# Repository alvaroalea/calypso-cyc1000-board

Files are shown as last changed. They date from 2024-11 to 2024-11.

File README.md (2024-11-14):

# The calypso board project

Calypso is just another middleboard based on the Arrow/Trenz cyc1000 board. This was born as a personal project to experiment with such board as it was delivered by Arrow Electronics as part of their European "Jump Start" Program for FPGAs.

THIS FORK is only to try to got a cheap way to order pcb with SMD components solder, please refer to the original project for any:

https://github.com/teiram/calypso-cyc1000-board

## Prices:
### 5 QTY
|Type of build: |  |  /5 |
|----|----|----|
|Only PCB | 1,89€+1,43€ = 4€ |  1€ |
|All smd (71)(but no 1 resistor, transistors, PCM5102, usb socket) |  43,25€+17,43€ =  61€ |  12€ |
|Only basic smd components + Diodes (62)(no 1C, 9R, 2Q, PCM, usb ) |  19,63€+17.xx€ =  38€ |  8€ |
|Only basic smd components (52)(previos - diodes) |  15,97€+16,68€ =  33€ |  7€ |

### 2QTY + 3 PCB
|Type of build: |  |  /2 |
|----|----|----|
|All smd (71)(but no 1 resistor, transistors, PCM5102, usb socket) | 40,75€+16,68€=57€-3€=55€ |  27€ |

### 20 QTY
|Type of build: |  |  /20 |
|----|----|----|
|All smd (71)(but no 1 resistor, transistors, PCM5102, usb socket) |  82,93€+42,74€ = 126€ |  6.5€ |
|Only basic smd components + Diodes  (62)(no 1C, 9R, 2Q, PCM, usb ) |  51,09€+41,41€ =  93€ |  5€ |

### 10 QTY
|Type of build: | |  /10 |
|---|---|---|
|All smd (71)(but no 1 resistor, transistors, PCM5102, usb socket)  | 53,17€+26,89€ =  80€ |  8€ |
|Only basic smd components + Diodes  (62)(no 1C, 9R, 2Q, PCM, usb ) | 27,19€+26,06€ =  54€ |  5.5€ |

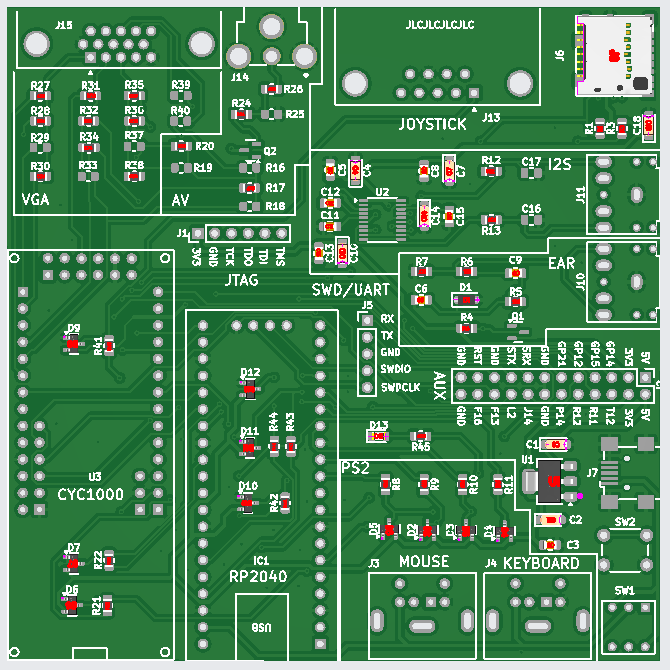
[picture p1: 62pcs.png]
Most economical option


# Original Doc:

The board takes ideas and design from other existing hobbyist project boards, embracing the following design principles:
- Doesn't try to support multiple FPGAs and/or MCUs. it's based on the CYC1000 board and an R2040 as MCU
- Follows the Mist ideas about IO, being the MCU the hub for most IO needs. This is convenient since the CYC1000 doesn't expose a big number of pins to the outside world.
- Tries to be compatible to some extent with Mist IO, therefore exposing a SPI bus mastered by the MCU to the FPGA, and the well known select signals CONF_DATA0, MIST_SS2, MIST_SS3 and MIST_SS4. This should ease the task of porting cores from Mist or boards with a similar design.
# Features
- VGA444 output via an standard VGA DB15 connector
- Optional AV output via a RCA connector. Both VGA and AV share FPGA pins.
- DB9 connector for a joystick with up to 2 fire buttons
- SD card
- Two PS/2 connectors
- Power button
- Reset button
- Ear input
- I2S audio output
- Mini USB for main power supply
- AUX connector for extension, exposing free pins in both the Cyc1000 and the RP2040.

# Pinout
As of preview version 0.2 this is the pinout description

Pinout Calypso Pinouts

# Support firmware
Firmware for the RP2040 MCU is so far a fork of zxmicrojack for RP2040 based Mist (https://github.com/ZXMicroJack/mist-firmware-rp2040) modified for calypso. The aim is to develop a specific and more minimalistic firmware since the current one was used mostly for board validation purposes. The forked firmware can be found here: https://github.com/teiram/mist-firmware-rp2040 

> [!NOTE]  
> I'm happy to share that we have now an oficial firmware for the board. It's still in a preliminary stage but should support most of the needed feature for Mist compatibility > and you can find it here: https://github.com/teiram/calypso-firmware/

# Disclaimer
This is a personal project I started with the support of the RetroWiki FPGA Dev community (thank you guys). There is no aim for commercial benefit neither I will provide any warranty or support beyond what my free time allows for. Feel free to build the board for your personal use, or a limited batch of units for your pals. It works for me, but I tested it with a very limited set of hardware, so your milleage may vary.
Enjoy ;)

# Errata, issues
## Version 0.3
- Fixed Q2 footprint and updated values for C16 and C17. This version is so far untested, but since Q2 issue was fixed manually without need ro reroute the board again, there are good chances it's safe to use.
  
## Version 0.2
- Q2 footprint is wrong. The schematic shows a BC547 but a SMD BC847 was intended. Unfortunately the pinout doesn´t match. So in case you want to use the composite video output you need to adjust it accordingly. A BC847 can be installed by rotating it 90º counterclockwise, what makes soldering a bit trickier but it can be done.
- The board supports RP2040 clones known as YD-2040 by VCC-GND studio. An official RP2040 won´t work completely due to:
  - The SWD header in the official RP2040 has 3 pins instead of 4 pins, so you cannot take advantage of the SWD/UART connector but you can still attach your SWD device directly to the RP2040.
  - YD-2040 exposes GPIO 23 on pin 37, which is not the case for in the official RP2040. Unfortunately GPIO23 is used for one of the DB9 joystick directions, and therefore a DB9 joystick won't work properly with an official RP2040
  - The YD-2040 doesn´t expose VBUS on the breakboard pins, therefore USB devices can only be used if they are self-powered or connected through a self-powered USB hub. The official RP2040 exposes VBUS and therefore it would be possible to power the bus without the need of a powered hub. But since the design was based on the YD-2040 there is no provision for that. This might be addressed in future releases.

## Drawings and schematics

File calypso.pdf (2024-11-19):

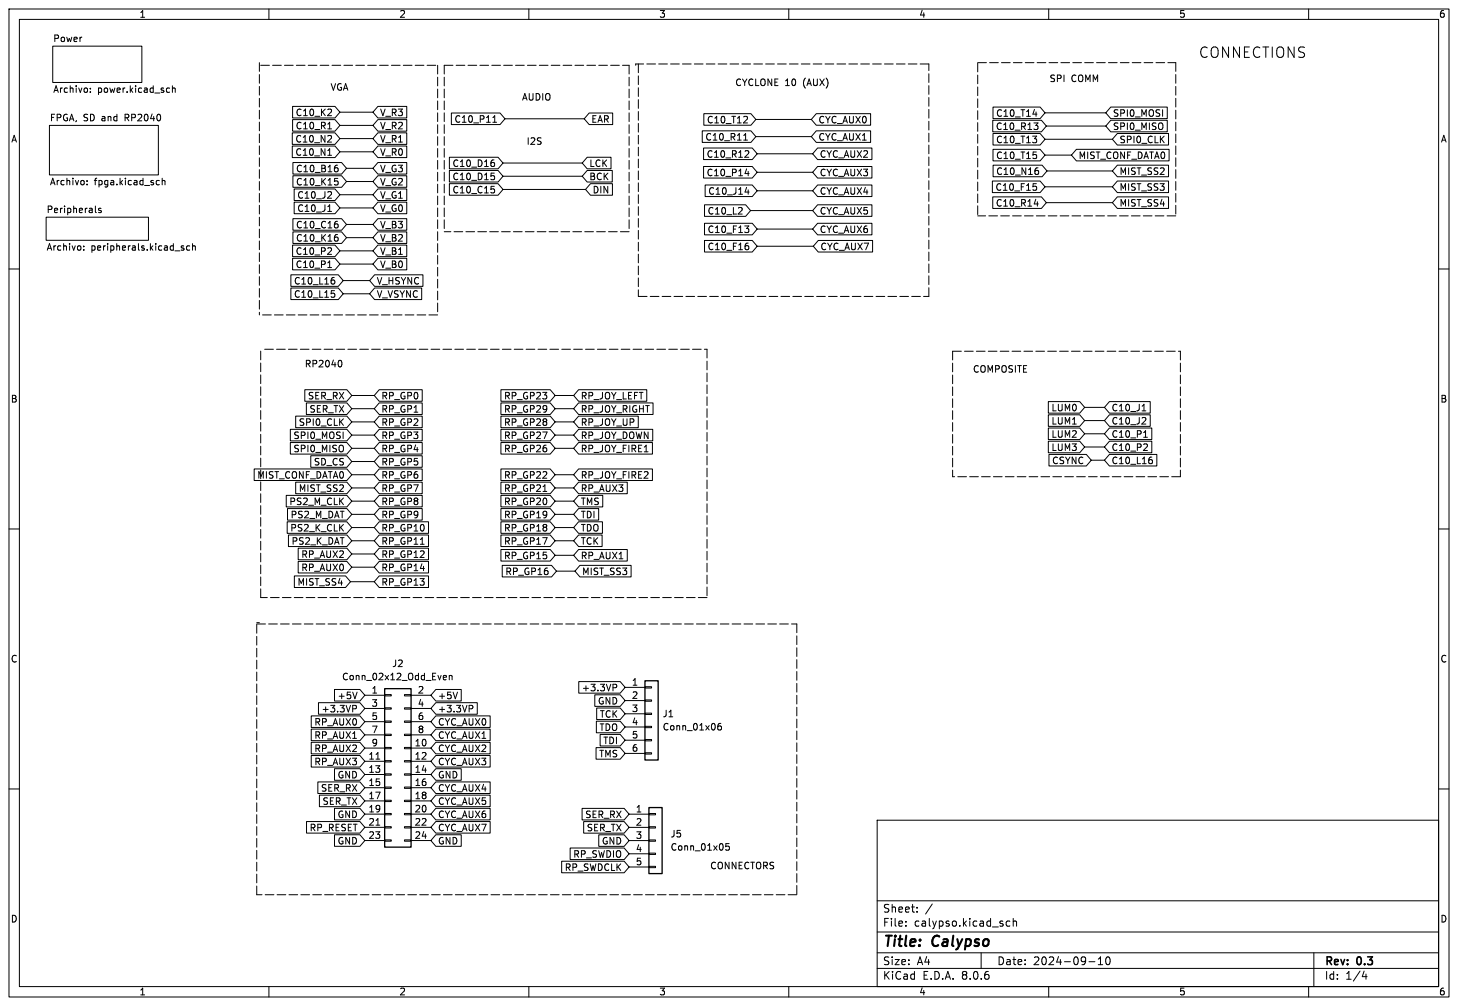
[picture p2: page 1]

Peripherals Archivo: peripherals.kicad_sch FPGA, SD and RP2040 Archivo: fpga.kicad_sch

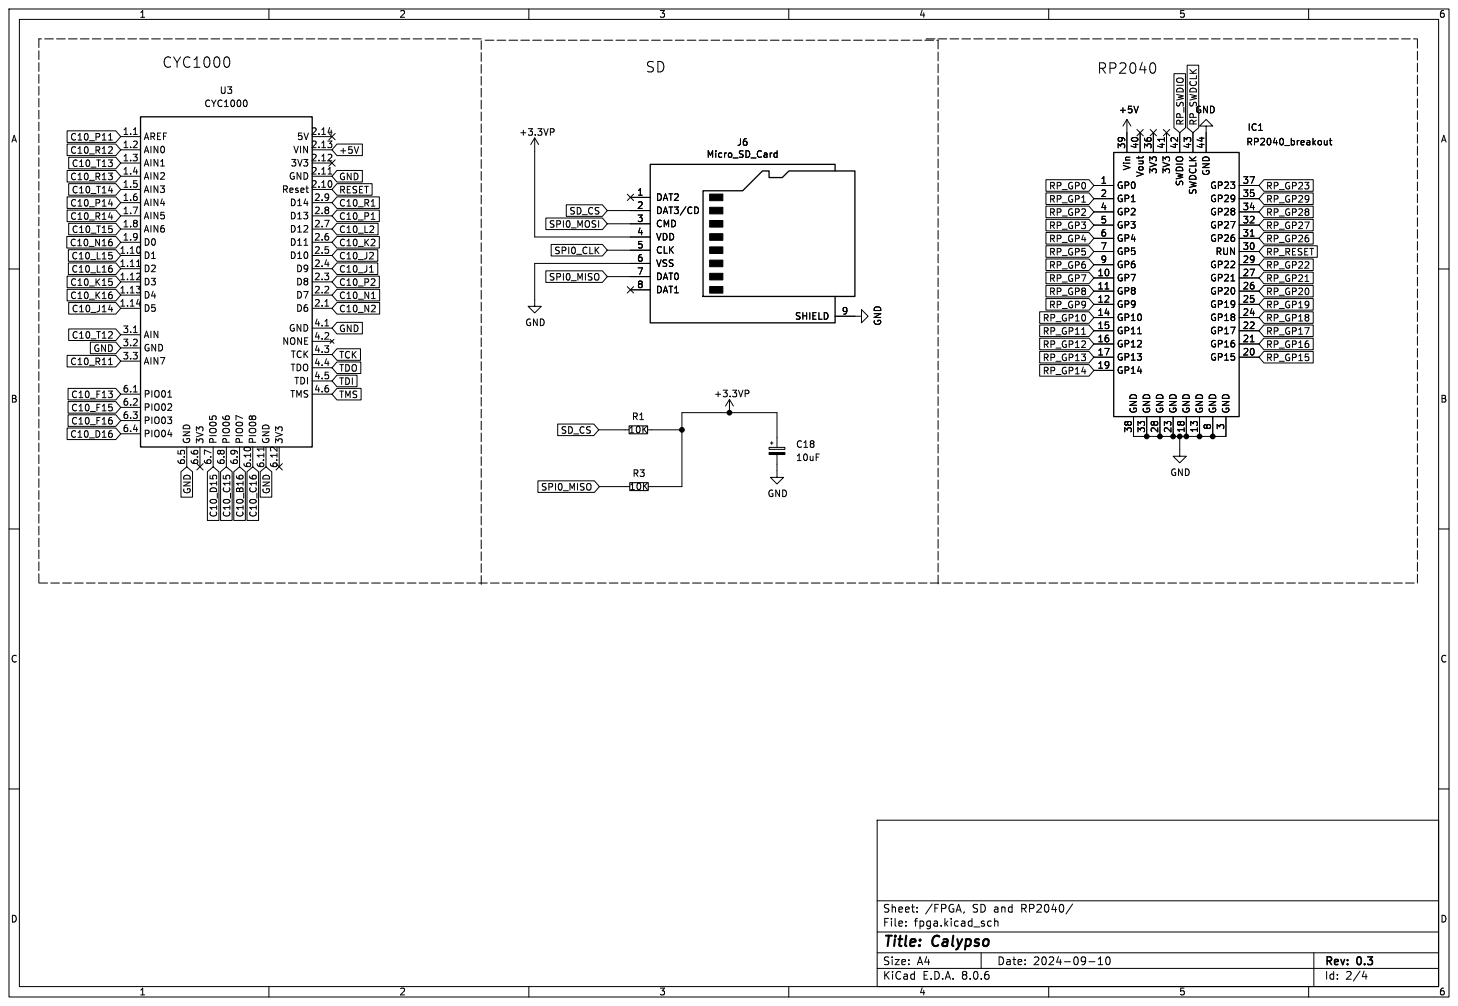
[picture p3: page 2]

3 RUN 30 GP26 31 GP27 32 GND 33 GP28 34 GP29 35 3V3 36 GP23 37 GND 38 Vin 39 GP2 4 Vout 40 3V3 41 SWDIO 42 SWDCLK 43 GND 44 GP3 5 GP4 6 GP5 7 GND

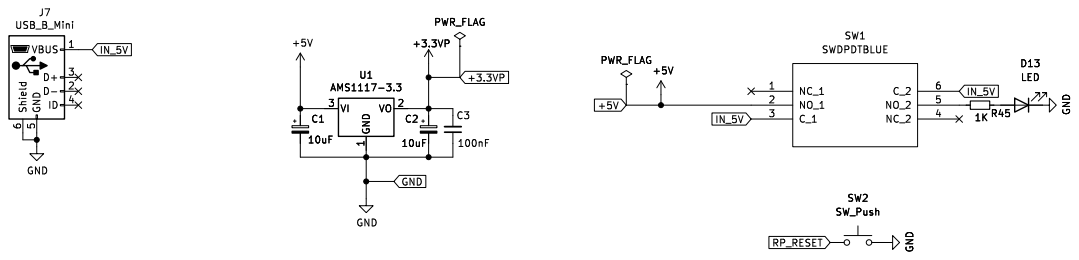
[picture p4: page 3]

File: power.kicad_sch Sheet: /Power/
Id: 3/4 Title: Calypso

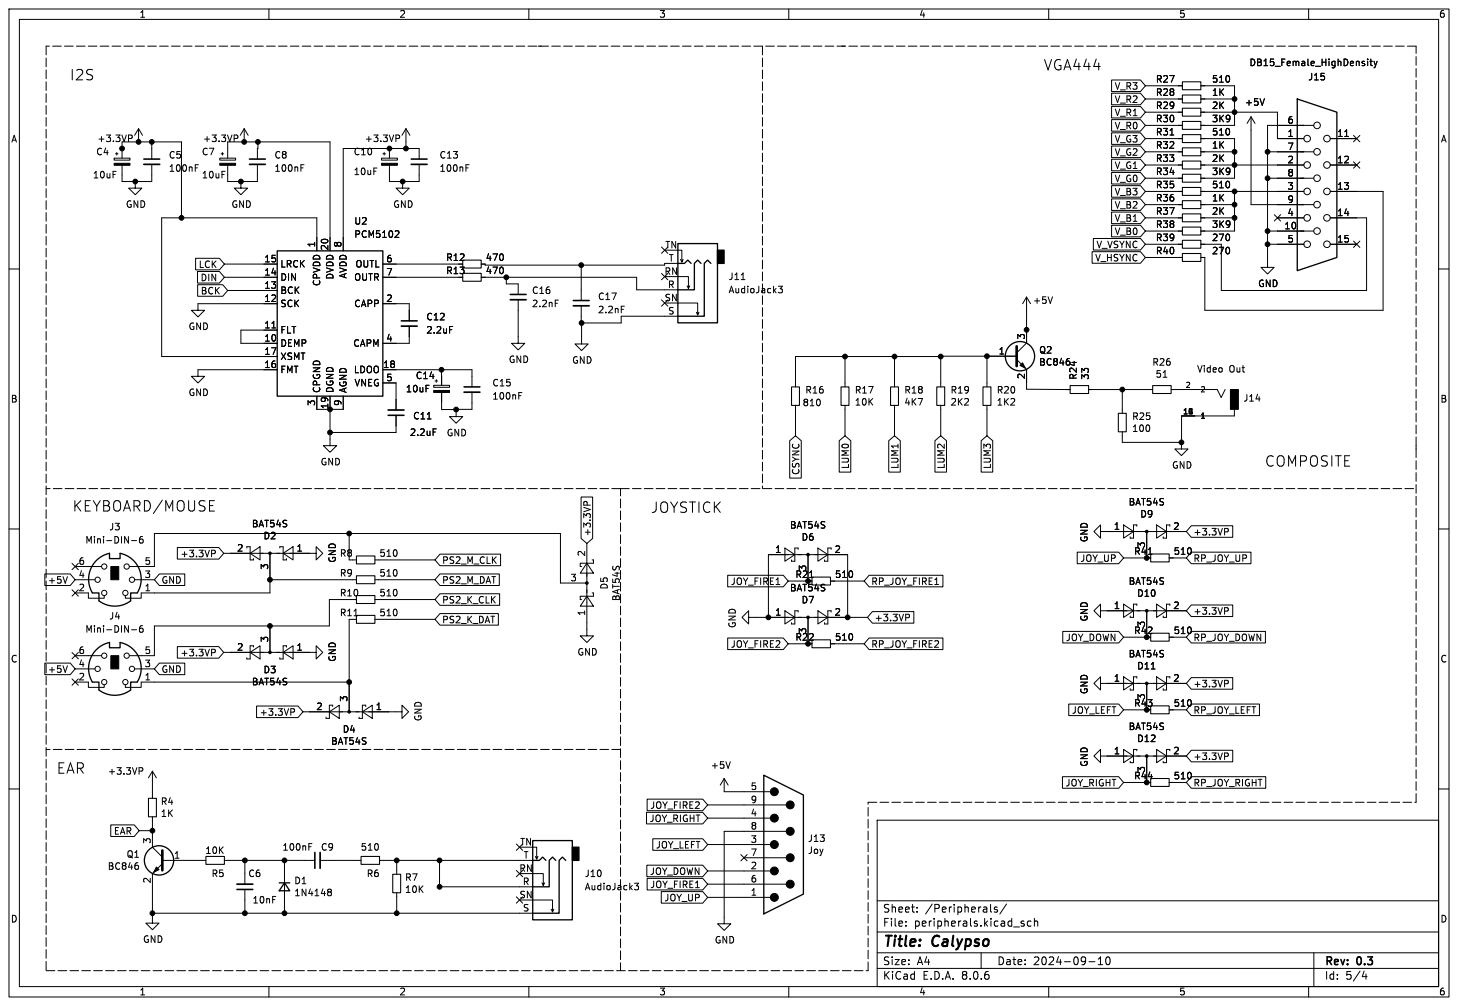
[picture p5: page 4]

1 DEMP 10 FLT 11 SCK 12 BCK 13 DIN 14

3 CAPM 4 VNEG 5 OUTL 6 OUTR 7 AVDD

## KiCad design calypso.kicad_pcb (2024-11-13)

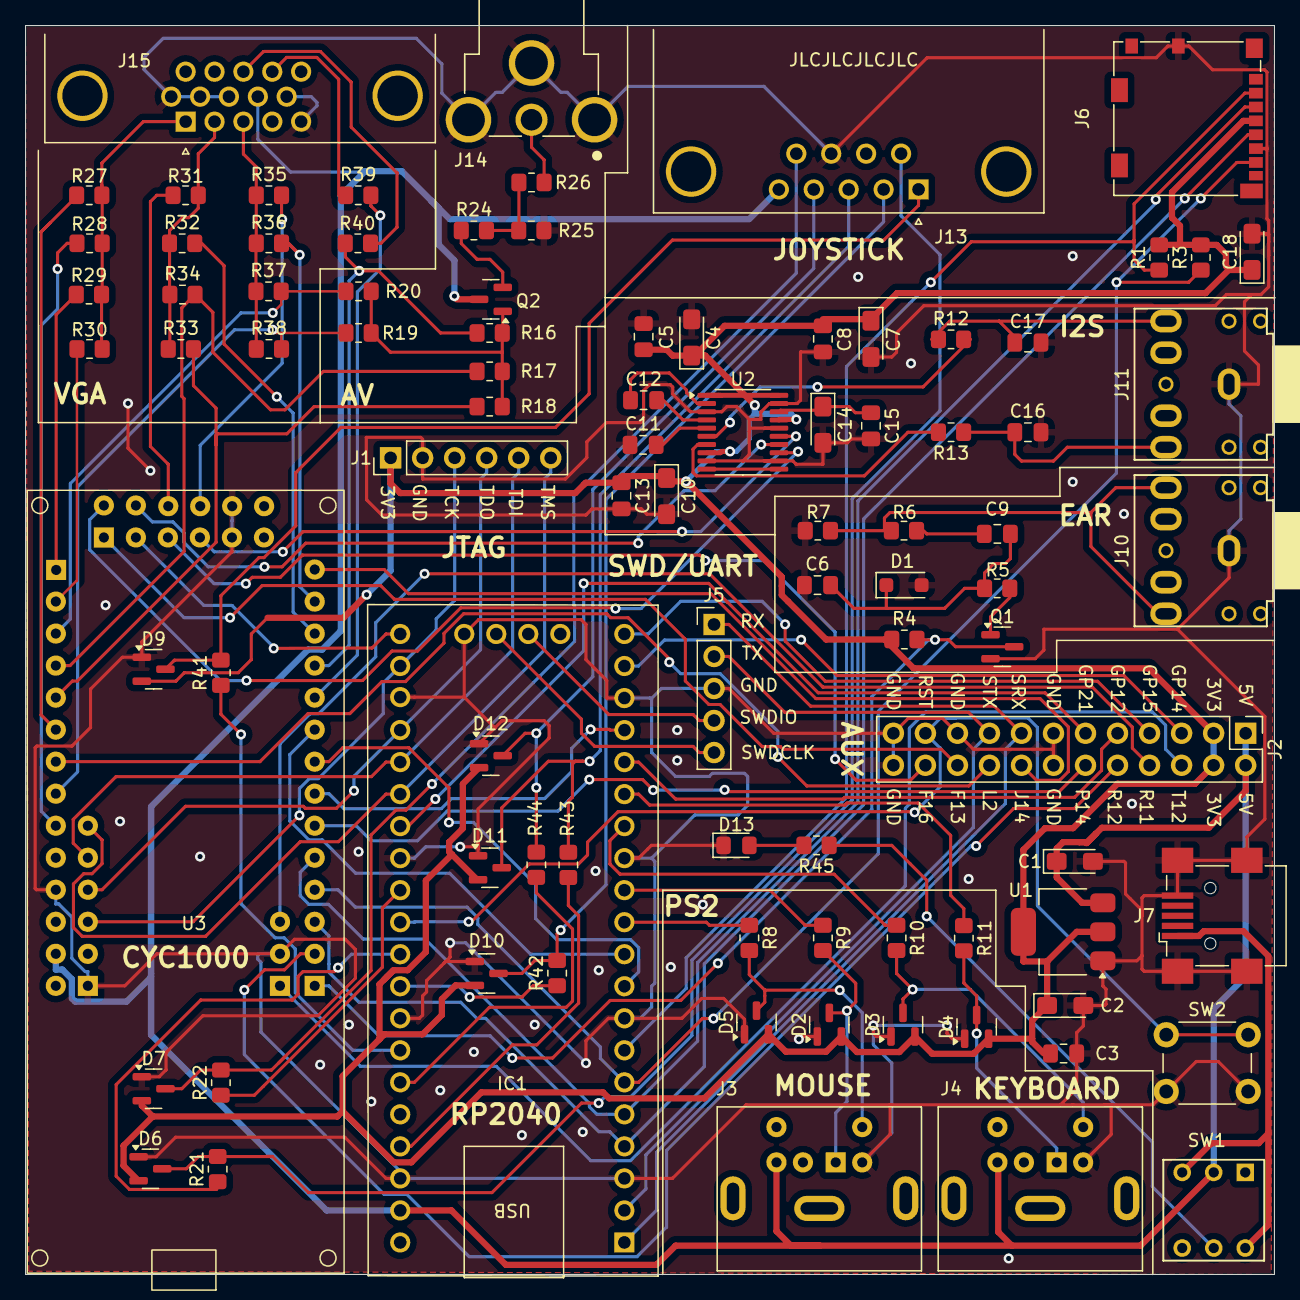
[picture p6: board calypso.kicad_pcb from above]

Board: 2 copper layers, 99.1 x 99.1 mm, 91 parts (0 on the bottom side), 95 nets.

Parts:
C1, C2, C4, C7, C10, C14, C18: 10uF; CP_EIA-3216-12_Kemet-S_Pad1.58x1.35mm_HandSolder
C3, C5, C8, C9, C13, C15: 100nF; C_0805_2012Metric_Pad1.18x1.45mm_HandSolder
C6: 10nF; C_0805_2012Metric_Pad1.18x1.45mm_HandSolder
C11, C12: 2.2uF; C_0805_2012Metric_Pad1.18x1.45mm_HandSolder
C16, C17: 2.2nF; C_0805_2012Metric_Pad1.18x1.45mm_HandSolder
D1: 1N4148; D_SOD-123F
D2, D3, D4, D5, D6, D7, D9, D10, D11, D12: BAT54S; SOT-23
D13: LED; LED_0805_2012Metric_Pad1.15x1.40mm_HandSolder
IC1: RP2040_breakout; RP2040-Breakout_swd
J1: Conn_01x06; PinHeader_1x06_P2.54mm_Vertical
J2: Conn_02x12_Odd_Even; PinHeader_2x12_P2.54mm_Vertical
J3, J4: Mini-DIN-6; Connector_Mini-DIN_Female_6Pin_2rows
J5: Conn_01x05; PinHeader_1x05_P2.54mm_Vertical
J6: Micro_SD_Card; microSD_HC_Molex_104031-0811
J7: USB_B_Mini; USB_Mini-B_Wuerth_65100516121_Horizontal
J10, J11: AudioJack3; pj307
J13: Joy; DSUB-9_Male_Horizontal_P2.77x2.84mm_EdgePinOffset9.90mm_Hou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
J14: Video Out; CUI_RCJ-013
J15: DB15_Female_HighDensity; DSUB-15-HD_Female_Horizontal_P2.29x1.98mm_EdgePinOffset3.03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
Q1, Q2: BC846; SOT-23
R1, R3, R5, R7, R17: 10K; R_0805_2012Metric_Pad1.20x1.40mm_HandSolder
R4, R28, R32, R36, R45: 1K; R_0805_2012Metric_Pad1.20x1.40mm_HandSolder
R6, R8, R9, R10, R11, R21, R22, R27, R31, R35, R41, R42, R43, R44: 510; R_0805_2012Metric_Pad1.20x1.40mm_HandSolder
R12, R13: 470; R_0805_2012Metric_Pad1.20x1.40mm_HandSolder
R16: 810; R_0805_2012Metric_Pad1.20x1.40mm_HandSolder
R18: 4K7; R_0805_2012Metric_Pad1.20x1.40mm_HandSolder
R19: 2K2; R_0805_2012Metric_Pad1.20x1.40mm_HandSolder
R20: 1K2; R_0805_2012Metric_Pad1.20x1.40mm_HandSolder
R24: 33; R_0805_2012Metric_Pad1.20x1.40mm_HandSolder
R25: 100; R_0805_2012Metric_Pad1.20x1.40mm_HandSolder
R26: 51; R_0805_2012Metric_Pad1.20x1.40mm_HandSolder
R29, R33, R37: 2K; R_0805_2012Metric_Pad1.20x1.40mm_HandSolder
R30, R34, R38: 3K9; R_0805_2012Metric_Pad1.20x1.40mm_HandSolder
R39, R40: 270; R_0805_2012Metric_Pad1.20x1.40mm_HandSolder
SW1: SWDPDTBLUE; SW_PUSH_x2
SW2: SW_Push; SW_PUSH_6mm_H4.3mm
U1: AMS1117-3.3; SOT-223-3_TabPin2
U2: PCM5102; TSSOP-20_4.4x6.5mm_P0.65mm
U3: CYC1000; cyc1000

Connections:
+3.3VP: C2.1, C3.2, C4.1, C5.1, C7.1, C8.1, C10.1, C13.1, C18.1, D2.2, D3.2, D4.2, D5.2, D6.2, D7.2, D9.2, D10.2, D11.2, D12.2, J1.1, J2.3, J2.4, J6.4 (VDD), R1.2, R3.2, R4.1, U1.2 (VO), U2.1 (CPVDD), U2.8 (AVDD), U2.17 (XSMT), U2.20 (DVDD)
+5V: C1.1, IC1.39 (Vin), J2.1, J2.2, J3.4, J4.4, J13.5, J15.9, Q2.3 (C), SW1.2 (NO_1), U1.3 (VI), U3.2.13 (VIN)
BCK: U2.13 (BCK), U3.6.7 (PIO05)
C10_B16: R31.2, U3.6.9 (PIO07)
C10_C15: U2.14 (DIN), U3.6.8 (PIO06)
C10_C16: R35.2, U3.6.10 (PIO08)
C10_D16: U2.15 (LRCK), U3.6.4 (PIO04)
C10_F13: J2.20, U3.6.1 (PIO01)
C10_F15: IC1.21 (GP16), U3.6.2 (PIO02)
C10_F16: J2.22, U3.6.3 (PIO03)
C10_J1: R17.2, R34.2, U3.2.4 (D9)
C10_J2: R18.2, R33.2, U3.2.5 (D10)
C10_J14: J2.16, U3.1.14 (D5)
C10_K2: R27.2, U3.2.6 (D11)
C10_K15: R32.2, U3.1.12 (D3)
C10_K16: R36.2, U3.1.13 (D4)
C10_L2: J2.18, U3.2.7 (D12)
C10_L15: R39.2, U3.1.10 (D1)
C10_L16: R16.2, R40.2, U3.1.11 (D2)
C10_N1: R30.2, U3.2.2 (D7)
C10_N2: R29.2, U3.2.1 (D6)
C10_N16: IC1.10 (GP7), U3.1.9 (D0)
C10_P1: R19.2, R38.2, U3.2.8 (D13)
C10_P2: R20.2, R37.2, U3.2.3 (D8)
C10_P11: Q1.3 (C), R4.2, U3.1.1 (AREF)
C10_P14: J2.12, U3.1.6 (AIN4)
C10_R1: R28.2, U3.2.9 (D14)
C10_R11: J2.8, U3.3.3 (AIN7)
C10_R12: J2.10, U3.1.2 (AIN0)
C10_R13: IC1.6 (GP4), J6.7 (DAT0), R3.1, U3.1.4 (AIN2)
C10_R14: IC1.17 (GP13), U3.1.7 (AIN5)
C10_T12: J2.6, U3.3.1 (AIN)
C10_T13: IC1.4 (GP2), J6.5 (CLK), U3.1.3 (AIN1)
C10_T14: IC1.5 (GP3), J6.3 (CMD), U3.1.5 (AIN3)
C10_T15: IC1.9 (GP6), U3.1.8 (AIN6)
GND: C1.2, C2.2, C3.1, C4.2, C5.2, C6.1, C7.2, C8.2, C10.2, C11.1, C13.2, C14.2, C15.2, C16.2, C17.2, C18.2, D1.2 (A), D2.1, D3.1, D4.1, D5.1, D6.1, D7.1, D9.1, D10.1, D11.1, D12.1, D13.1 (K), IC1.3 (GND), IC1.8 (GND), IC1.13 (GND), IC1.18 (GND), IC1.23 (GND), IC1.28 (GND), IC1.33 (GND), IC1.38 (GND), IC1.44 (GND), J1.2, J2.13, J2.14, J2.19, J2.23, J2.24, J3.3, J4.3, J5.3, J6.6 (VSS), J6.9 (SHIELD), J7.5 (GND), J7.6 (Shield), J10.S, J11.S, J13.8, J14.1A (1), J14.1B (1), J14.1C (1), J15.5, J15.6, J15.7, J15.8, J15.10, Q1.2 (E), R7.2, R25.2, SW2.2, U1.1 (GND), U2.3 (CPGND), U2.9 (AGND), U2.12 (SCK), U2.16 (FMT), U2.19 (DGND), U3.2.11 (GND), U3.3.2 (GND), U3.4.1 (GND), U3.6.5 (GND), U3.6.11 (GND)
IN_5V: J7.1 (VBUS), SW1.3 (C_1), SW1.6 (C_2)
JOY_DOWN: D10.3, J13.2, R42.2
JOY_FIRE1: D6.3, J13.6, R21.2
JOY_FIRE2: D7.3, J13.9, R22.2
JOY_LEFT: D11.3, J13.3, R43.2
JOY_RIGHT: D12.3, J13.4, R44.2
JOY_UP: D9.3, J13.1, R41.2
unnamed: C9.2, R6.1
unnamed: C16.1, J11.R, R13.1
unnamed: C17.1, J11.T, R12.1
unnamed: C6.2, C9.1, D1.1 (K), R5.2
unnamed: D2.3, J3.1, R9.2
unnamed: D3.3, J4.5, R10.2
unnamed: D4.3, J4.1, R11.2
unnamed: D5.3, J3.5, R8.2
unnamed: D13.2 (A), R45.2
unnamed: J10.R, J10.T, R6.2, R7.1
unnamed: J14.2, R26.1
unnamed: J15.1, R27.1, R28.1, R29.1, R30.1
unnamed: J15.2, R31.1, R32.1, R33.1, R34.1
unnamed: J15.3, R35.1, R36.1, R37.1, R38.1
unnamed: J15.13, R40.1
unnamed: J15.14, R39.1
unnamed: Q1.1 (B), R5.1
unnamed: Q2.1 (B), R16.1, R17.1, R18.1, R19.1, R20.1
unnamed: Q2.2 (E), R24.1
unnamed: R24.2, R25.1, R26.2
unnamed: R45.1, SW1.5 (NO_2)
unnamed: C12.2, U2.4 (CAPM)
unnamed: C12.1, U2.2 (CAPP)
unnamed: U2.10 (DEMP), U2.11 (FLT)
unnamed: C14.1, C15.1, U2.18 (LDOO)
unnamed: R12.2, U2.6 (OUTL)
unnamed: R13.2, U2.7 (OUTR)
unnamed: C11.2, U2.5 (VNEG)
PS2_K_CLK: IC1.14 (GP10), R10.1
PS2_K_DAT: IC1.15 (GP11), R11.1
PS2_M_CLK: IC1.11 (GP8), R8.1
PS2_M_DAT: IC1.12 (GP9), R9.1
RP_AUX0: IC1.19 (GP14), J2.5
RP_AUX1: IC1.20 (GP15), J2.7
RP_AUX2: IC1.16 (GP12), J2.9
RP_AUX3: IC1.27 (GP21), J2.11
RP_GP0: IC1.1 (GP0), J2.15, J5.1
RP_GP1: IC1.2 (GP1), J2.17, J5.2
RP_GP5: IC1.7 (GP5), J6.2 (DAT3/CD), R1.1
RP_GP17: IC1.22 (GP17), J1.3, U3.4.3 (TCK)
RP_GP18: IC1.24 (GP18), J1.4, U3.4.4 (TDO)
RP_GP19: IC1.25 (GP19), J1.5, U3.4.5 (TDI)
RP_GP20: IC1.26 (GP20), J1.6, U3.4.6 (TMS)
RP_GP22: IC1.29 (GP22), R22.1
RP_GP23: IC1.37 (GP23), R43.1
RP_GP26: IC1.31 (GP26), R21.1
RP_GP27: IC1.32 (GP27), R42.1
RP_GP28: IC1.34 (GP28), R41.1
RP_GP29: IC1.35 (GP29), R44.1
RP_RESET: IC1.30 (RUN), J2.21, SW2.1
RP_SWDCLK: IC1.43 (SWDCLK), J5.5
RP_SWDIO: IC1.42 (SWDIO), J5.4
